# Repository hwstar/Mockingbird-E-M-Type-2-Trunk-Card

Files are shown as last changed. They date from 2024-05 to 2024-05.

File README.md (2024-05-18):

# Mockingbird-E-M-Type-2-Trunk-Card
An E&amp;M Type 2 trunk card for the Mockingbird Telephone Exchange

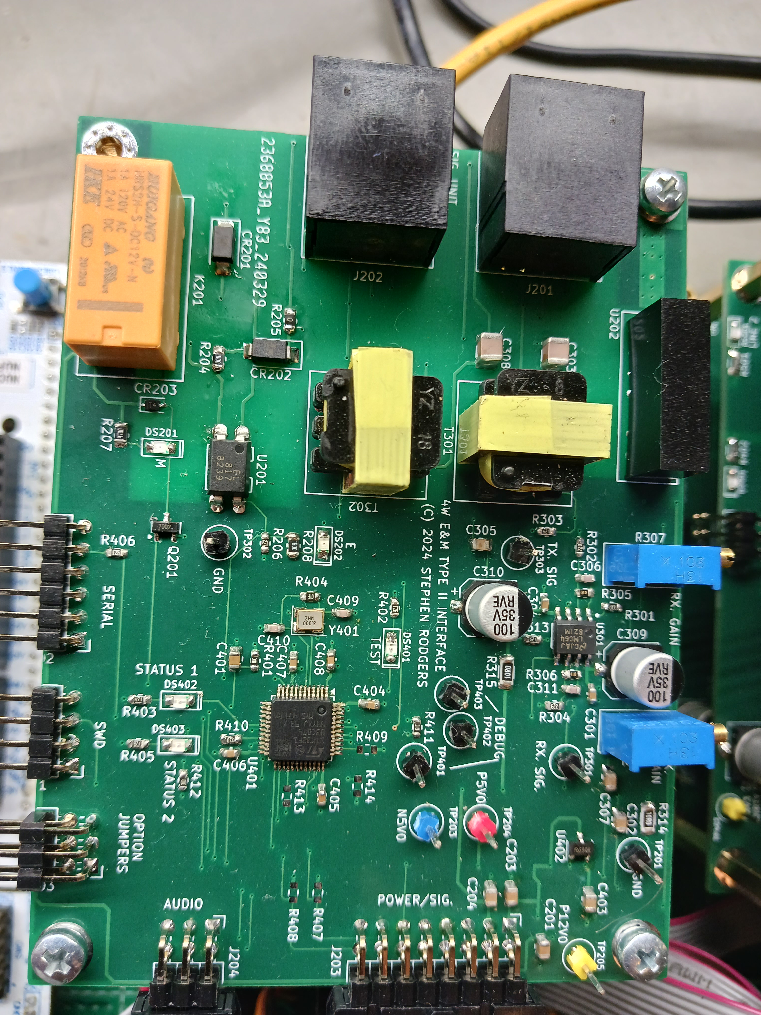
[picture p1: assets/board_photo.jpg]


An interface card design for the Mockingbird Telephone Exchange. 

Features: 
* Provides one E&M type 2 interface
* STM32F103C8T6 microcontroller.
* Isolated local -48VDC supply for the M lead current
* Dry contacts for the E-lead
* Separate  RJ45 jacks for signalling and trunk pinouts.
* Uses standard 4 pair EIA568B Network cable pinout.
* Adjustable audio levels
* Accessed from the Main Microcontroller over I2C
* ATTEN signal to main microcontroller to tell it when there is an event to service.
* 4 Wire transformer isolated audio interface converts the balanced interface audio to unbalanced.
* Design in KiCAD 8.0.

The main project website is on hackaday.io here: https://hackaday.io/project/196044-mockingbird-telephone-exchange

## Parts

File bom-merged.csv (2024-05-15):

Item | Part Number | Qty | Reference(s) | Title/Description | Value on Schematic | Manufacturer | Manufacturer Part Number | Footprint
1 | 800003-106 | 6 | C201,C203,C204,C302,C305,C307 | CAP,0805,10u,25V,X5R | 10U | Murata Electronics | GRM21BR61E106KA73L | C_0805_2012Metric
1 | 800003-106 | 6 | C201,C203,C204,C302,C305,C307 | CAP,0805,10u,25V,X5R | 10U | Samsung Electromechanics | CL21A106KAYNNNE | C_0805_2012Metric
1 | 800003-106 | 6 | C201,C203,C204,C302,C305,C307 | CAP,0805,10u,25V,X5R | 10U | LCSC | C15850 | C_0805_2012Metric
2 | 800423-474 | 2 | C202,C205 | CAP,0805,0.47UF,50V,5%,X7R | 0.47u | LCSC | C520080 | C_0805_2012Metric
2 | 800423-474 | 2 | C202,C205 | CAP,0805,0.47UF,50V,5%,X7R | 0.47u | Yageo | CC0805JKX7R9BB474 | C_0805_2012Metric
3 | 800003-475 | 1 | C206 | CAP,0805,4.7u,25V,X5R | 4.7u | Taiyo-Yuden | TMK212ABJ475KG-T | C_0805_2012Metric
3 | 800003-475 | 1 | C206 | CAP,0805,4.7u,25V,X5R | 4.7u | LCSC | C1779,C386082 | C_0805_2012Metric
3 | 800003-475 | 1 | C206 | CAP,0805,4.7u,25V,X5R | 4.7u | Samsung Electromechanics | CL21A475KAQNNNE | C_0805_2012Metric
4 | 800063-104 | 7 | C301,C304,C404-C408 | CAP,0603,0.1u,50V,X7R | 0.1u | Kyocera AVX | 06035C104KAT2A | C_0603_1608Metric
4 | 800063-104 | 7 | C301,C304,C404-C408 | CAP,0603,0.1u,50V,X7R | 0.1u | Yageo | CC0603KRX7R9BB104 | C_0603_1608Metric
4 | 800063-104 | 7 | C301,C304,C404-C408 | CAP,0603,0.1u,50V,X7R | 0.1u | LCSC | C14663 | C_0603_1608Metric
5 | 800428-335 | 2 | C303,C308 | CAP,1210,3.3UF,10%,100V,X7R | 3.3u | LCSC | C692313 | C_1210_3225Metric
5 | 800428-335 | 2 | C303,C308 | CAP,1210,3.3UF,10%,100V,X7R | 3.3u | Prosperity Dielectrics | FS32X335K101EGG | C_1210_3225Metric
6 | 800002-330 | 2 | C306,C311 | CAP,0603,33p,50V,C0G | 33p | Samsung Electromechanics | CL10C330JB8NNNC | C_0603_1608Metric
6 | 800002-330 | 2 | C306,C311 | CAP,0603,33p,50V,C0G | 33p | LCSC | C1663 | C_0603_1608Metric
7 | 800421-107 | 2 | C309,C310 | CAP,ALUM_ELECT,100uF,35V,ESR 600mOHM,6.3MM,2000 HR | 100U | LCSC | C2836437 | CP_Elec_6.3x7.7
7 | 800421-107 | 2 | C309,C310 | CAP,ALUM_ELECT,100uF,35V,ESR 600mOHM,6.3MM,2000 HR | 100U | KNSCHA | RVE100UF35V67RV0072 | CP_Elec_6.3x7.7
8 | 800238-105 | 1 | C401 | CAP,0805,1u,50V,X7R | 1u | WALSIN TECH CORP | 0805B105K500CT | C_0805_2012Metric
8 | 800238-105 | 1 | C401 | CAP,0805,1u,50V,X7R | 1u | Samsung Electromechanics | CL21B105KBFNNNE | C_0805_2012Metric
8 | 800238-105 | 1 | C401 | CAP,0805,1u,50V,X7R | 1u | LCSC | C28323 | C_0805_2012Metric
9 | 800003-226 | 1 | C403 | CAP,0805,22u,25V,X5R | 22u | LCSC | C45783 | C_0805_2012Metric
9 | 800003-226 | 1 | C403 | CAP,0805,22u,25V,X5R | 22u | Samsung Electromechanics | CL21A226MAQNNNE | C_0805_2012Metric
10 | 800002-220 | 2 | C409,C410 | CAP,0603,22p,50V,C0G | 22p | LCSC | C1653 | C_0603_1608Metric
10 | 800002-220 | 2 | C409,C410 | CAP,0603,22p,50V,C0G | 22p | Samsung Electromechanics | CL10C220JB8NNNC | C_0603_1608Metric
11 | 800335-064 | 2 | CR201,CR202 | DIODE,TVS,64V,BIDIRECT,SMA | SMAJ64CA | LCSC | C2898428 | D_SMA
11 | 800335-064 | 2 | CR201,CR202 | DIODE,TVS,64V,BIDIRECT,SMA | SMAJ64CA | YFW | SMAJ64CA | D_SMA
12 | 800264-102 | 1 | CR203 | DIODE,SWITCHING,75V,SOD-323 | 1N4148WS | LCSC | C2128 | D_SOD-323
12 | 800264-102 | 1 | CR203 | DIODE,SWITCHING,75V,SOD-323 | 1N4148WS | JIANGSU CHANGJIANG ELECTRONICS TECHNOLOGY CO LTD. | 1N4148WS | D_SOD-323
13 | 800113-102 | 5 | DS201,DS202,DS401-DS403 | LED,GREEN,0805 | LEDGRN-SAR | LCSC | C434435 | LED0805
13 | 800113-102 | 5 | DS201,DS202,DS401-DS403 | LED,GREEN,0805 | LEDGRN-SAR | Yongsu Photoelectric | SZYY0805YG | LED0805
14 | 800429-101 | 2 | J201,J202 | CONN,JACK,MODULAR,8P8C,PLASTIC,PTH | RJ45 | LCSC | C3000197 | CONN_RJ45_HCTL_HC_RJ45_058_1_6
14 | 800429-101 | 2 | J201,J202 | CONN,JACK,MODULAR,8P8C,PLASTIC,PTH | RJ45 | HCTL | HC-RJ45-058-1-6 | CONN_RJ45_HCTL_HC_RJ45_058_1_6
15 | 800343-102 | 1 | J203 | CONN,HDR,2 POS.,STR,PTH,2.54MM,TIN | Conn_02x08_Odd_Even | DEALON | DZ254R-11-02-63 | PinHeader_2x08_P2.54mm_Horizontal
15 | 800343-102 | 1 | J203 | CONN,HDR,2 POS.,STR,PTH,2.54MM,TIN | Conn_02x08_Odd_Even | LCSC | C2935908 | PinHeader_2x08_P2.54mm_Horizontal
16 | 800425-106 | 2 | J204,J403 | CONN,HDR,STRIP,DUAL ROW,RA,PTH,2X3,0.254 MM PITCH | Conn_02x03_Odd_Even | LCSC | C2935935 | PinHeader_2x03_P2.54mm_Horizontal
16 | 800425-106 | 2 | J204,J403 | CONN,HDR,STRIP,DUAL ROW,RA,PTH,2X3,0.254 MM PITCH | Conn_02x03_Odd_Even | DEALON | DZ254W-22-06-69 | PinHeader_2x03_P2.54mm_Horizontal
17 | 800383-104 | 1 | J401 | HEADER,STRIP,RA,4 POS,0.254MM PITCH | CONN4 | DEALON | DZ254W-11-04-65 | PinHeader_1x04_P2.54mm_Horizontal
17 | 800383-104 | 1 | J401 | HEADER,STRIP,RA,4 POS,0.254MM PITCH | CONN4 | LCSC | C2935929 | PinHeader_1x04_P2.54mm_Horizontal
18 | 800383-106 | 1 | J402 | HEADER,STRIP,RA,6 POS,0.254MM PITCH | CONN6 | LCSC | C2935931 | PinHeader_1x06_P2.54mm_Horizontal
18 | 800383-106 | 1 | J402 | HEADER,STRIP,RA,6 POS,0.254MM PITCH | CONN6 | DEALON | DZ254W-11-06-65 | PinHeader_1x06_P2.54mm_Horizontal
19 | 800279-012 | 1 | K201 | RELAY, TELECOM, DIP, DPDT, 12V | RELAY_2RT | HUIGANG | HRS2H-S-DC12V-N | RELAY-DPDT-HRS2H
19 | 800279-012 | 1 | K201 | RELAY, TELECOM, DIP, DPDT, 12V | RELAY_2RT | LCSC | C60087 | RELAY-DPDT-HRS2H
20 | 800441-047 | 3 | L201-L203 | IND,1206,4.7UH,0.7A,+/-20% | 4.7uH | FH (Guangdong Fenghua Advanced Tech) | CMP321609UD4R7MT | L_1206_3216Metric
20 | 800441-047 | 3 | L201-L203 | IND,1206,4.7UH,0.7A,+/-20% | 4.7uH | LCSC | C139250 | L_1206_3216Metric
21 | 800346-101 | 1 | Q201 | XSTR,MOSFET,SOT-23,N-CH,60V,115MA | 2N7002 | LCSC | C8545 | SOT-23
21 | 800346-101 | 1 | Q201 | XSTR,MOSFET,SOT-23,N-CH,60V,115MA | 2N7002 | JIANGSU CHANGJIANG ELECTRONICS TECHNOLOGY CO LTD. | 2N7002 | SOT-23
22 | 800248-472 | 2 | R201,R202 | RES,2512,4.7K OHM, 1%,1W | 4.7K | LCSC | C473645 | R_2512_6332Metric
22 | 800248-472 | 2 | R201,R202 | RES,2512,4.7K OHM, 1%,1W | 4.7K | Uni-Royal | 25121WF4701T4E | R_2512_6332Metric
23 | 800057-123 | 1 | R203 | RES,1206,12K OHM,1%,1/4W | 12K | LCSC | C965064 | R_1206_3216Metric
23 | 800057-123 | 1 | R203 | RES,1206,12K OHM,1%,1/4W | 12K | Uni-Royal | NQ06W4F1202T5E | R_1206_3216Metric
24 | 800235-181 | 2 | R204,R208 | RES,0805,180,1% | 180 | Uni-Royal | 0805W8F1800T5E | R_0805_2012Metric
24 | 800235-181 | 2 | R204,R208 | RES,0805,180,1% | 180 | LCSC | C25270 | R_0805_2012Metric
25 | 800235-000 | 1 | R205 | RES,0805,0,1% | 0 | LCSC | C17477 | R_0805_2012Metric
25 | 800235-000 | 1 | R205 | RES,0805,0,1% | 0 | Uni-Royal | 0805W8F0000T5E | R_0805_2012Metric
26 | 800022-470 | 1 | R206 | RES,0603,4.70K OHM,1%,E24 | 4.7K | Resistor.Today | AECR0603F4K70K9 | R_0603_1608Metric
26 | 800022-470 | 1 | R206 | RES,0603,4.70K OHM,1%,E24 | 4.7K | Uni-Royal | 0603WAF4701T5E | R_0603_1608Metric
26 | 800022-470 | 1 | R206 | RES,0603,4.70K OHM,1%,E24 | 4.7K | LCSC | C23162,C328364 | R_0603_1608Metric
27 | 800235-471 | 1 | R207 | RES,0805,470,1% | 470 | LCSC | C17710 | R_0805_2012Metric
27 | 800235-471 | 1 | R207 | RES,0805,470,1% | 470 | Uni-Royal | 0805W8F4700T5E | R_0805_2012Metric
28 | 800020-330 | 2 | R301,R410 | RES,0603,33 OHM,1%,E24 | 33 | Uni-Royal | 0603WAF330JT5E | R_0603_1608Metric
28 | 800020-330 | 2 | R301,R410 | RES,0603,33 OHM,1%,E24 | 33 | LCSC | C23140 | R_0603_1608Metric
29 | 800023-220 | 2 | R302,R304 | RES,0603,22K OHM,1% | 22K | LCSC | C31850 | R_0603_1608Metric
29 | 800023-220 | 2 | R302,R304 | RES,0603,22K OHM,1% | 22K | Uni-Royal | 0603WAF2202T5E | R_0603_1608Metric
30 | 800021-620 | 2 | R303,R313 | RES,0603,620 OHM,1%,E24 | 620 | LCSC | C23220 | R_0603_1608Metric
30 | 800021-620 | 2 | R303,R313 | RES,0603,620 OHM,1%,E24 | 620 | Uni-Royal | 0603WAF6200T5E | R_0603_1608Metric
31 | 800024-100 | 2 | R305,R306 | RES,0603,100K OHM,1%,E24 | 100K | LCSC | C25803 | R_0603_1608Metric
31 | 800024-100 | 2 | R305,R306 | RES,0603,100K OHM,1%,E24 | 100K | Uni-Royal | 0603WAF1003T5E | R_0603_1608Metric
32 | 800430-103 | 2 | R307,R309 | RES,TRIMMER,3296,HORIZ,PTH,10K,10%,0.5W | 10K | BOCHEN | 3296X-1-103 | Potentiometer_Bourns_3296X_Horizontal_Screw_SS
32 | 800430-103 | 2 | R307,R309 | RES,TRIMMER,3296,HORIZ,PTH,10K,10%,0.5W | 10K | LCSC | C118955 | Potentiometer_Bourns_3296X_Horizontal_Screw_SS
33 | 800057-100 | 2 | R314,R315 | RES,1206,10 OHM,1%,1/4W | 10 | LCSC | C844016 | R_1206_3216Metric
33 | 800057-100 | 2 | R314,R315 | RES,1206,10 OHM,1%,1/4W | 10 | Vishay | CRCW120610R0FKEB | R_1206_3216Metric
34 | 800023-100 | 3 | R401,R411,R412 | RES,0603,10.0K OHM,1% | 10K | WALSIN TECH CORP | MR06X1002FTL | R_0603_1608Metric
34 | 800023-100 | 3 | R401,R411,R412 | RES,0603,10.0K OHM,1% | 10K | Uni-Royal | 0603WAF1002T5E | R_0603_1608Metric
34 | 800023-100 | 3 | R401,R411,R412 | RES,0603,10.0K OHM,1% | 10K | LCSC | C25804 | R_0603_1608Metric
35 | 800021-470 | 4 | R402,R403,R405,R406 | RES,0603,470 OHM,1%,E24 | 470 | LCSC | C23179 | R_0603_1608Metric
35 | 800021-470 | 4 | R402,R403,R405,R406 | RES,0603,470 OHM,1%,E24 | 470 | Uni-Royal | 0603WAF4700T5E | R_0603_1608Metric
36 | 800025-100 | 1 | R404 | RES,0603,1M OHM,1%,E24 | 1M | Yageo | RC0603FR-071ML | R_0603_1608Metric
36 | 800025-100 | 1 | R404 | RES,0603,1M OHM,1%,E24 | 1M | Uni-Royal | 0603WAF1004T5E | R_0603_1608Metric
36 | 800025-100 | 1 | R404 | RES,0603,1M OHM,1%,E24 | 1M | LCSC | C22935 | R_0603_1608Metric
37 | 800427-101 | 2 | T301,T302 | XFMR,AUDIO,600:600 OHMS,PTH | XFMR-AUDIO-COUPLING | Open Market | N/A | XFMR_AUDIO_COUPLING_PP3.575_SPC_11_HOLE_0.85
38 | 800116-101 | 10 | TP201,TP203-TP205,TP301-TP303,TP401-TP403 | CONN,HDR,1CKT,0.1PITCH,BERGSTRIP | TESTPINTPSQ025 | Open Market | N/A | TESTPIN
39 | 800362-101 | 1 | U201 | OPTOCOUPLER,NPN,SOP-4 | EL817S1(B)(TU)-F | LCSC | C63268 | DIP-4_W7.62mm
39 | 800362-101 | 1 | U201 | OPTOCOUPLER,NPN,SOP-4 | EL817S1(B)(TU)-F | EVERLIGHT | EL817S1(B)(TU)-F | DIP-4_W7.62mm
40 | 800440-101 | 1 | U202 | MODULE,DC-DC CONV,ISO,10.8-13.2VIN,+/-24VOUT,1W | A1224S-1WR3 | LCSC | C5369401 | A1224S-1WR3
40 | 800440-101 | 1 | U202 | MODULE,DC-DC CONV,ISO,10.8-13.2VIN,+/-24VOUT,1W | A1224S-1WR3 | Ylptech | A1224S-1WR3 | A1224S-1WR3
41 | 800272-101 | 1 | U301 | IC,OP-AMP,DUAL,RRIO,1.3MHZ,GBW,SOIC8 | LMC6482 | LCSC | C1346083 | SOIC8N-SAR
41 | 800272-101 | 1 | U301 | IC,OP-AMP,DUAL,RRIO,1.3MHZ,GBW,SOIC8 | LMC6482 | Texas Instruments | LMC6482AIM/NOPB | SOIC8N-SAR
42 | 800405-101 | 1 | U401 | IC,MPU,ARM CORTEX M3,64KB,LQFP-48 | STM32F103C8Tx | LCSC | C8734 | LQFP-48_7x7mm_P0.5mm
42 | 800405-101 | 1 | U401 | IC,MPU,ARM CORTEX M3,64KB,LQFP-48 | STM32F103C8Tx | ST Microelectronics | STM32F103C8T6 | LQFP-48_7x7mm_P0.5mm
43 | 800187-101 | 1 | U402 | IC,VREG,LDO,500MA,3.3V,SOT23 | ME6211A33M3G-N | Nanjing Micro One Elec | ME6211A33M3B-N | SOT23-3-SAR-V2
43 | 800187-101 | 1 | U402 | IC,VREG,LDO,500MA,3.3V,SOT23 | ME6211A33M3G-N | LCSC | C168807 | SOT23-3-SAR-V2
44 | 800412-008 | 1 | Y401 | CRYSTAL,8MHZ,12PF,10PPM,SMT,3225 | 8.0M | LCSC | C5308003 | Crystal_SMD_3225-4Pin_3.2x2.5mm
44 | 800412-008 | 1 | Y401 | CRYSTAL,8MHZ,12PF,10PPM,SMT,3225 | 8.0M | Shenzhen Yajingxin Electron Co.,Ltd | TX32258M4FBDD2T | Crystal_SMD_3225-4Pin_3.2x2.5mm
45 | XXXXXX-XXX | 0 |  | DNI | DNI | DNI | DNI | DNI

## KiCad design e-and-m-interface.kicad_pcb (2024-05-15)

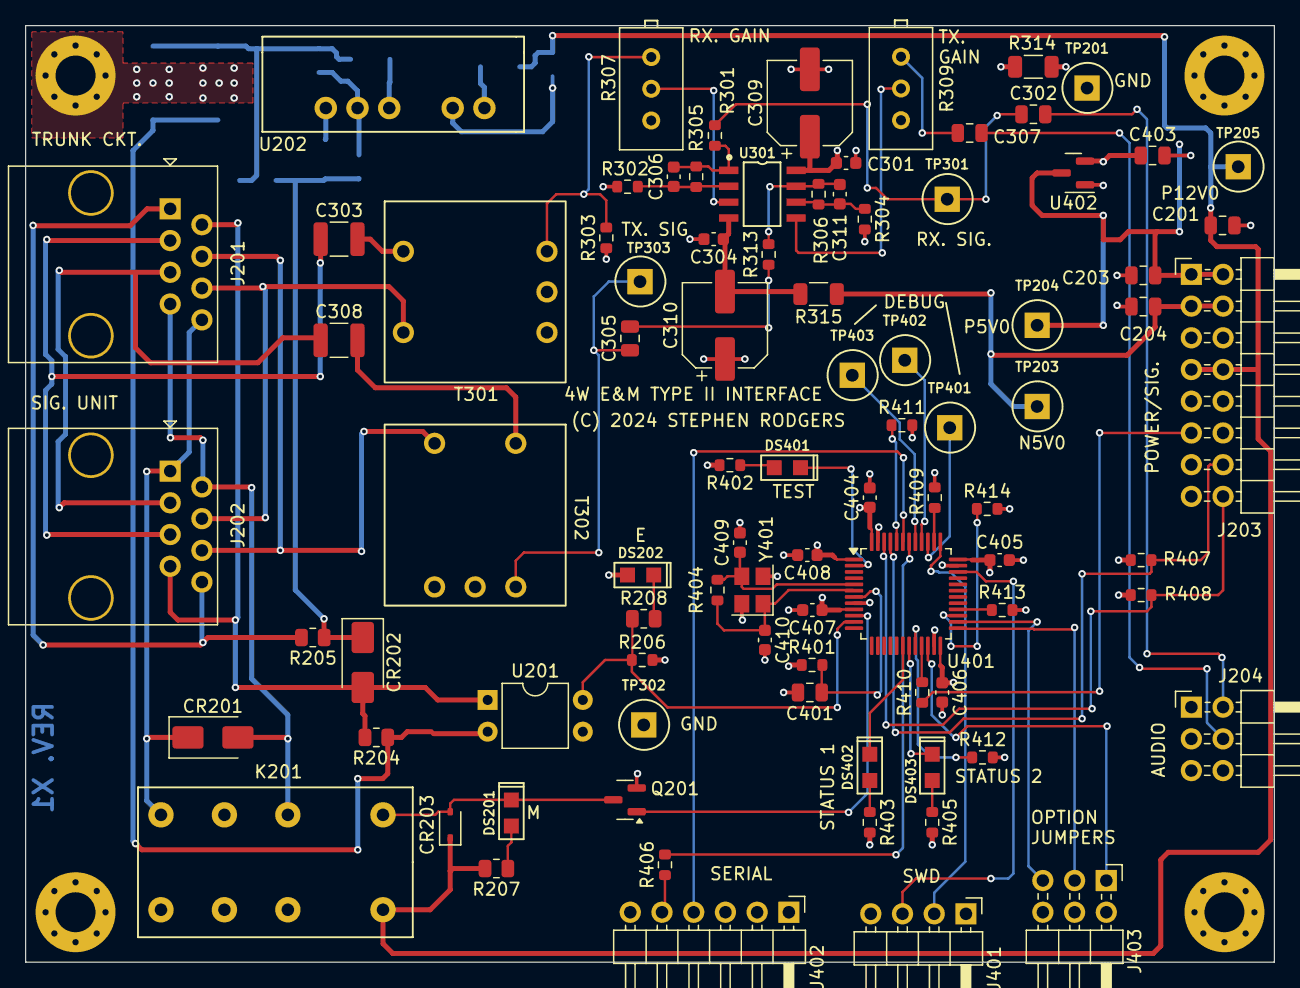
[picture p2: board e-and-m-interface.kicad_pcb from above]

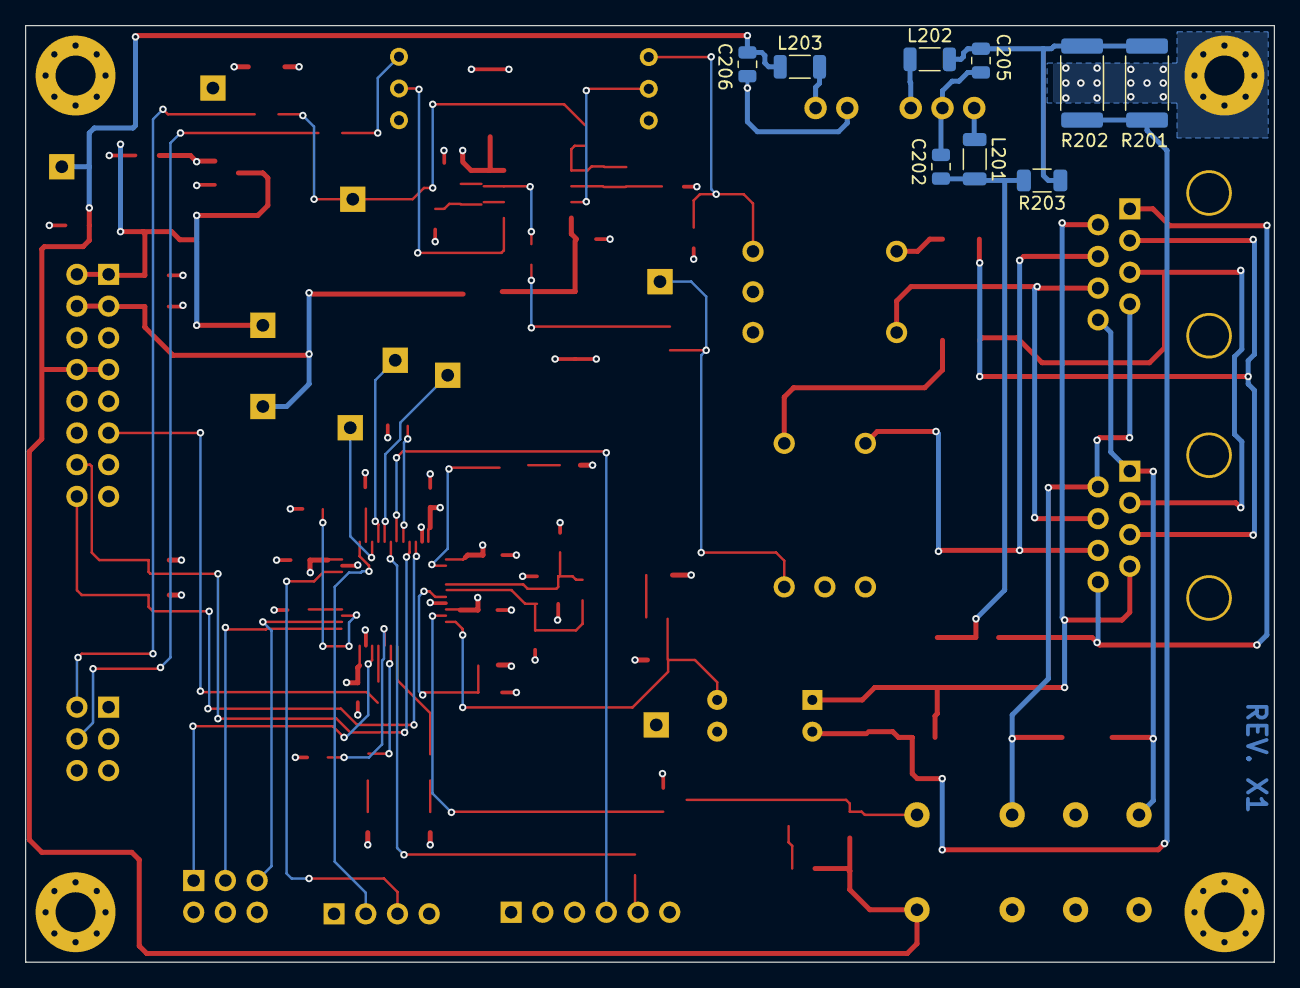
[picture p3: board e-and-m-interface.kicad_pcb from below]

Board: 4 copper layers, 100.0 x 75.0 mm, 101 parts (9 on the bottom side), 71 nets.

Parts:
C201, C203, C204: 10u; C_0805_2012Metric
C202, C205: 0.47u; C_0805_2012Metric
C206: 4.7u; C_0805_2012Metric
C301, C304, C404, C405, C406, C407, C408: 0.1u; C_0603_1608Metric
C302, C305, C307: 10U; C_0805_2012Metric
C303, C308: 3.3u; C_1210_3225Metric
C306, C311: 33p; C_0603_1608Metric
C309, C310: 100U; CP_Elec_6.3x7.7
C401: 1u; C_0805_2012Metric
C403: 22u; C_0805_2012Metric
C409, C410: 22p; C_0603_1608Metric
CR201, CR202: SMAJ64CA; D_SMA
CR203: 1N4148WS; D_SOD-323
DS201, DS202, DS401, DS402, DS403: LEDGRN-SAR; LED0805
J201, J202: RJ45; CONN_RJ45_HCTL_HC_RJ45_058_1_6
J203: Conn_02x08_Odd_Even; PinHeader_2x08_P2.54mm_Horizontal
J204, J403: Conn_02x03_Odd_Even; PinHeader_2x03_P2.54mm_Horizontal
J401: CONN4; PinHeader_1x04_P2.54mm_Horizontal
J402: CONN6; PinHeader_1x06_P2.54mm_Horizontal
K201: RELAY_2RT; RELAY-DPDT-HRS2H
L201, L202, L203: 4.7uH; L_1206_3216Metric
MH201, MH202, MH203, MH204: MountingHole_Pad; MountingHole_3.2mm_M3_Pad_Via
Q201: 2N7002; SOT-23
R201, R202: 4.7K; R_2512_6332Metric
R203: 12K; R_1206_3216Metric
R204, R208: 180; R_0805_2012Metric
R205: 0; R_0805_2012Metric
R206: 4.7K; R_0603_1608Metric
R207: 470; R_0805_2012Metric
R301, R410: 33; R_0603_1608Metric
R302, R304: 22K; R_0603_1608Metric
R303, R313: 620; R_0603_1608Metric
R305, R306: 100K; R_0603_1608Metric
R307, R309: 10K; Potentiometer_Bourns_3296X_Horizontal_Screw_SS
R314, R315: 10; R_1206_3216Metric
R401, R411, R412: 10K; R_0603_1608Metric
R402, R403, R405, R406: 470; R_0603_1608Metric
R404: 1M; R_0603_1608Metric
R407, R408: 2.2K; R_0603_1608Metric
R409, R413, R414: 0; R_0603_1608Metric
T301, T302: XFMR-AUDIO-COUPLING; XFMR_AUDIO_COUPLING_PP3.575_SPC_11_HOLE_0.85
TP201, TP203, TP204, TP205, TP301, TP302, TP303, TP401, TP402, TP403: TESTPINTPSQ025; TESTPIN
U201: EL817S1(B)(TU)-F; DIP-4_W7.62mm
U202: A1224S-1WR3
U301: LMC6482; SOIC8N-SAR
U401: STM32F103C8Tx; LQFP-48_7x7mm_P0.5mm
U402: ME6211A33M3G-N; SOT23-3-SAR-V2
Y401: 8.0M; Crystal_SMD_3225-4Pin_3.2x2.5mm

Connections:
/Top/ATTEN: J203.11, R410.1
/Top/Audio/N5V0_CLEAN: C304.1, C310.2, R315.2, U301.4 (V-)
/Top/Audio/P5V0_CLEAN: C301.2, C309.1, R314.2, U301.8 (V+)
/Top/Audio/RAP_TNV: C303.2, T301.1
/Top/Audio/XAP_TNV: C308.2, T302.1
/Top/Control/LEDN_TEST: DS401.2 (K), U401.2 (PC13)
/Top/Control/LED_STATUS_1_N: DS402.2 (K), U401.18 (PB0)
/Top/Control/LED_STATUS_2_N: DS403.2 (K), U401.19 (PB1)
/Top/Control/NRST: C401.1, R401.2, U401.7 (NRST)
/Top/Control/SW1: J403.1, U401.22 (PB11)
/Top/Control/SW2: J403.3, U401.25 (PB12)
/Top/Control/SW3: J403.5, U401.26 (PB13)
/Top/Control/SWCLK: J401.2, U401.37 (PA14)
/Top/Control/SWDIO: J401.3, U401.34 (PA13)
/Top/Control/TP1: TP401.1 (TP), U401.39 (PB3)
/Top/Control/TP2: TP402.1 (TP), U401.40 (PB4)
/Top/Control/TP3: TP403.1 (TP), U401.41 (PB5)
/Top/Control/UART_RX: J402.4, U401.43 (PB7)
/Top/Control/UART_TX: R406.2, U401.42 (PB6)
/Top/E_TNV: CR202.2 (A2), J201.2, J202.7, R204.2, U201.1
/Top/M_TNV: CR201.2 (A2), J201.7, J202.2, K201.12 (C2)
/Top/N5V0: C204.1, J203.3, J203.4, R315.1, TP203.1 (TP)
/Top/N48V0_RET_TNV: C202.1, CR202.1 (A1), L201.2, R203.2, R205.1
/Top/N48V0_TNV: C205.1, L202.2, R201.1, R202.1, R203.1
/Top/OPTO_LED_TNV: R201.2, R202.2, R204.1, U201.2
/Top/P3V3_CPU: C403.1, C404.1, C405.1, C406.1, C407.1, C408.1, DS202.1 (A), J401.4, R206.2, R401.1, R402.2, R403.2, R405.2, R407.1, R408.1, U401.1 (VBAT), U401.9 (VDDA), U401.24 (VDD), U401.36 (VDD), U401.48 (VDD), U402.2 (OUT)
/Top/P5V0: C203.1, J203.1, J203.2, R314.1, TP204.1 (TP), U402.3 (IN)
/Top/P12V0: C201.1, C206.1, CR203.1 (K), J203.7, J203.8, K201.8, L203.1, R207.2, TP205.1 (TP)
/Top/R1_TNV: J201.6, J202.4, T301.2
/Top/RXA: C302.2, J204.2
/Top/R_TNV: J201.4, J202.6, T302.2
/Top/SB_TNV: CR201.1 (A1), J201.8, J202.1, K201.16 (T2)
/Top/SCL: J203.14, R407.2, U401.45 (PB8)
/Top/SDA: J203.16, R408.2, U401.46 (PB9)
/Top/SEND_M: Q201.1 (G), U401.10 (PA0)
/Top/SENSE_E: R206.1, R208.1, U201.4, U401.11 (PA1)
/Top/SG_TNV: J201.1, J202.8, R205.2
/Top/T1_TNV: C303.1, J201.3, J202.5
/Top/TXA: C307.2, J204.4
/Top/T_TNV: C308.1, J201.5, J202.3
GND: C201.2, C203.2, C204.2, C206.2, C301.1, C304.2, C309.2, C310.1, C401.2, C403.2, C404.2, C405.2, C406.2, C407.2, C408.2, C409.2, C410.2, J203.9, J203.10, J203.12, J203.13, J203.15, J204.1, J204.3, J204.5, J204.6, J401.1, J402.1, J403.2, J403.4, J403.6, MH201.1, MH202.1, MH203.1, MH204.1, Q201.2 (S), R302.1, R303.1, R304.2, R307.1, R309.1, R409.2, R411.2, R412.2, R413.2, R414.2, T301.3, T302.3, TP201.1 (TP), TP302.1 (TP), U201.3, U202.2 (Vin-), U401.8 (VSSA), U401.23 (VSS), U401.35 (VSS), U401.47 (VSS), U402.1 (GND), Y401.2, Y401.4 (2)
unnamed: C305.2, R313.1
unnamed: C306.2, R301.1, R305.2, U301.1
unnamed: C307.1, R309.3
unnamed: C311.1, R306.1, R313.2, U301.7
unnamed: CR203.2 (A), DS201.2 (K), K201.9, Q201.3 (D)
unnamed: DS201.1 (A), R207.1
unnamed: DS202.2 (K), R208.2
unnamed: DS401.1 (A), R402.1
unnamed: DS402.1 (A), R403.1
unnamed: DS403.1 (A), R405.1
unnamed: J402.5, R406.1
unnamed: R303.2, R307.3, T301.5
unnamed: C305.1, T302.5, TP303.1 (TP)
unnamed: C302.1, R301.2, TP301.1 (TP)
unnamed: C202.2, C205.2, U202.5 (COM)
unnamed: L203.2, U202.1 (Vin+)
unnamed: L201.1, U202.6 (Vout+)
unnamed: L202.1, U202.4 (Vout-)
unnamed: R307.2, U301.3 (+)
unnamed: C306.1, R302.2, R305.1, U301.2 (-)
unnamed: R309.2, U301.5 (+)
unnamed: C311.2, R304.1, R306.2, U301.6 (-)
unnamed: R411.1, U401.44 (BOOT0)
unnamed: R409.1, U401.38 (PA15)
unnamed: R412.1, U401.20 (PB2)
unnamed: R410.2, U401.21 (PB10)
unnamed: R414.1, U401.27 (PB14)
unnamed: R413.1, U401.28 (PB15)
unnamed: C409.1, R404.1, U401.5 (PD0), Y401.3
unnamed: C410.1, R404.2, U401.6 (PD1), Y401.1

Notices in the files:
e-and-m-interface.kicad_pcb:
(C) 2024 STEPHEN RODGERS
